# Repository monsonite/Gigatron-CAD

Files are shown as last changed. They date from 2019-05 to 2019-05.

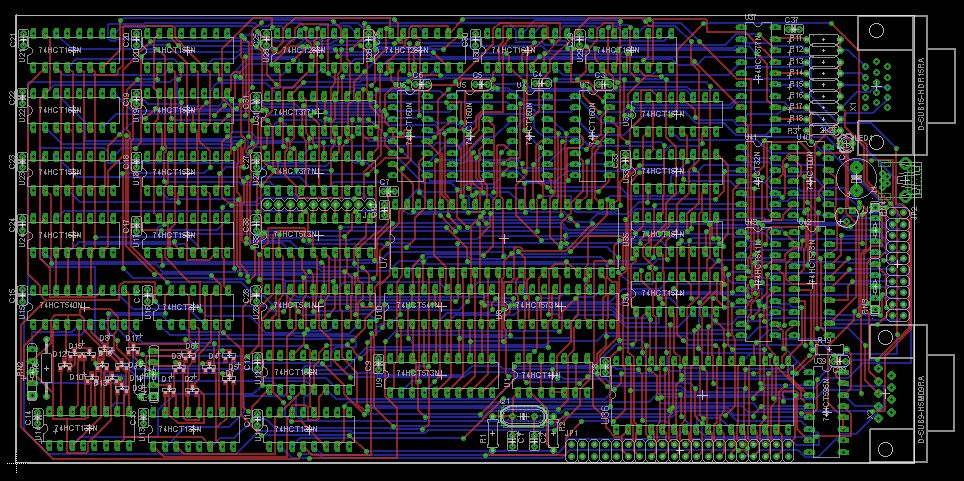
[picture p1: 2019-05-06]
Gig_8.JPG

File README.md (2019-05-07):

# Gigatron-CAD
Eagle CAD Files for the Gigatron TTL Computer - Based on the design by Marcel van Kervinck

These files contain the Gigatron TTL computer schematics transcribed to Eagle CAD - using the IC numbers used in the original KiCAD.

For anyone wanting to build a machine based on the Gigatron design, the Eagle CAD schematic offers a known starting point.

Minor alterations have been made to allow easier routing specifically in the ALU section, where all 74HCT153 multiplexers use the same multiplexer section - and the logic constants into the other mux are the same for all devices.

There are both PDF and PNG overviews of the ALU and Memory sections - a convenient way of representing the complete design.

Certain components substitutions have been made for convenience of layout or saving space

74HCT273 has been exchanged for the more bus friendly 74HCT573

74HCT240 and 74HCT244 have been exchanged for 74F540 and 74F541 - again to give better bus flow.

The diode matrix in the control unit now uses SOT-23 dual common anode diodes to reduce space

If you want to make a very compact Gigatron using 74F series SMT packages, Eagle CAD allows all of the major IC packages to be easily swapped to their SMT equivalents

Gigatron has been run at between 12.5 and 15MHz using 74F series ICS

The 128K byte RAM expansion and additional 8-bit input and 8-bit output ports (for SPI) are also included in this version

Use the .sch files at your own risk - I cannot guarantee that they are completely error free.

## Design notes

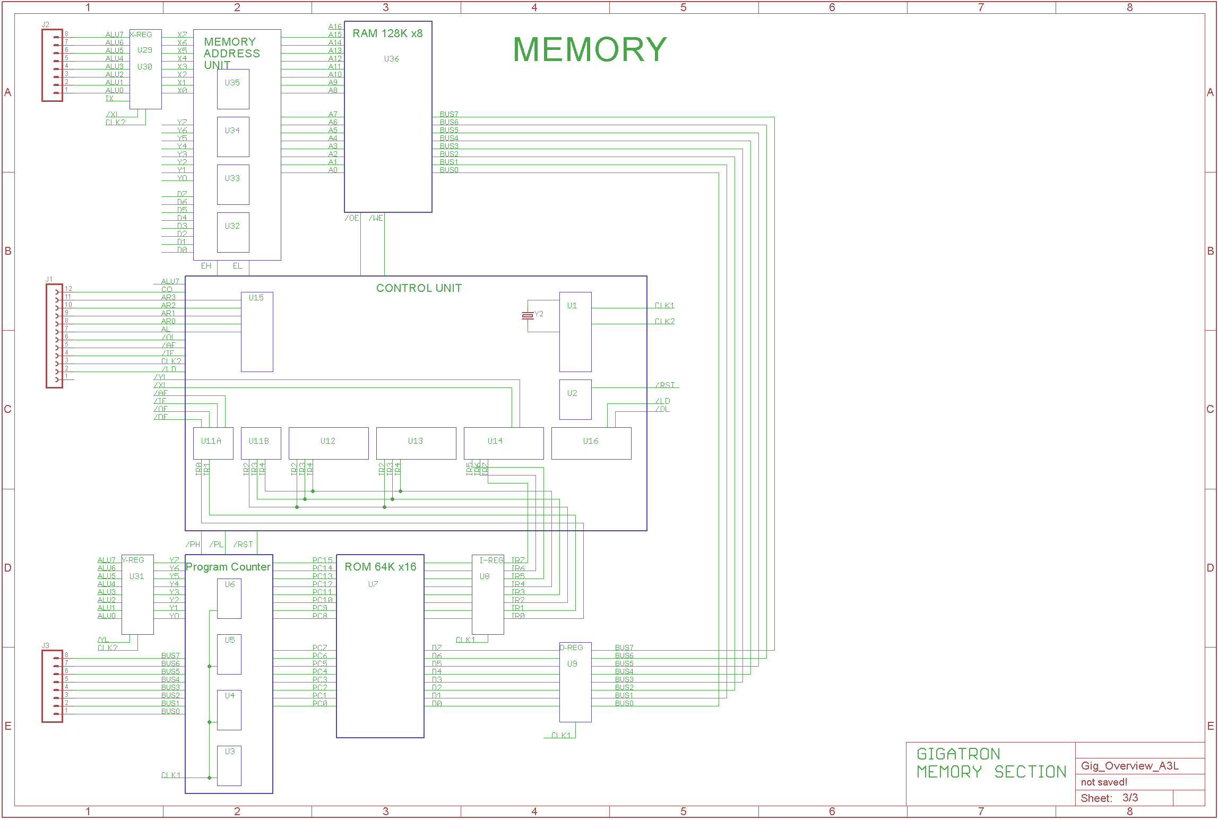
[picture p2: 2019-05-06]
Gig_Memory_A3L.png

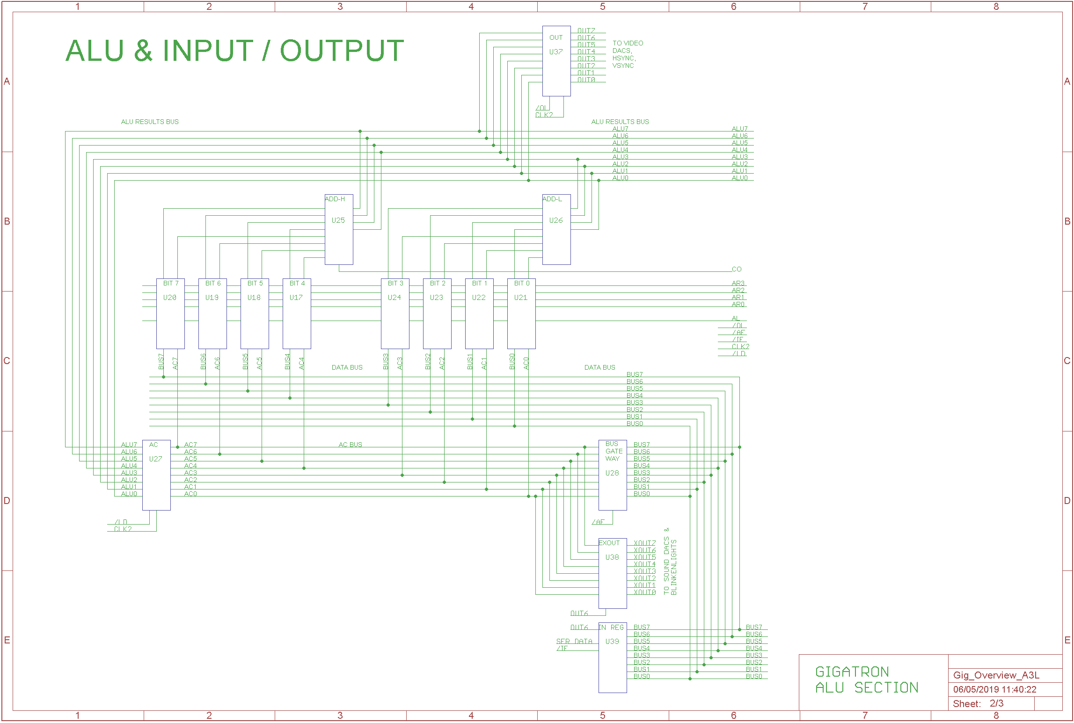
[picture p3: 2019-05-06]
Gig_ALU_A3L.png

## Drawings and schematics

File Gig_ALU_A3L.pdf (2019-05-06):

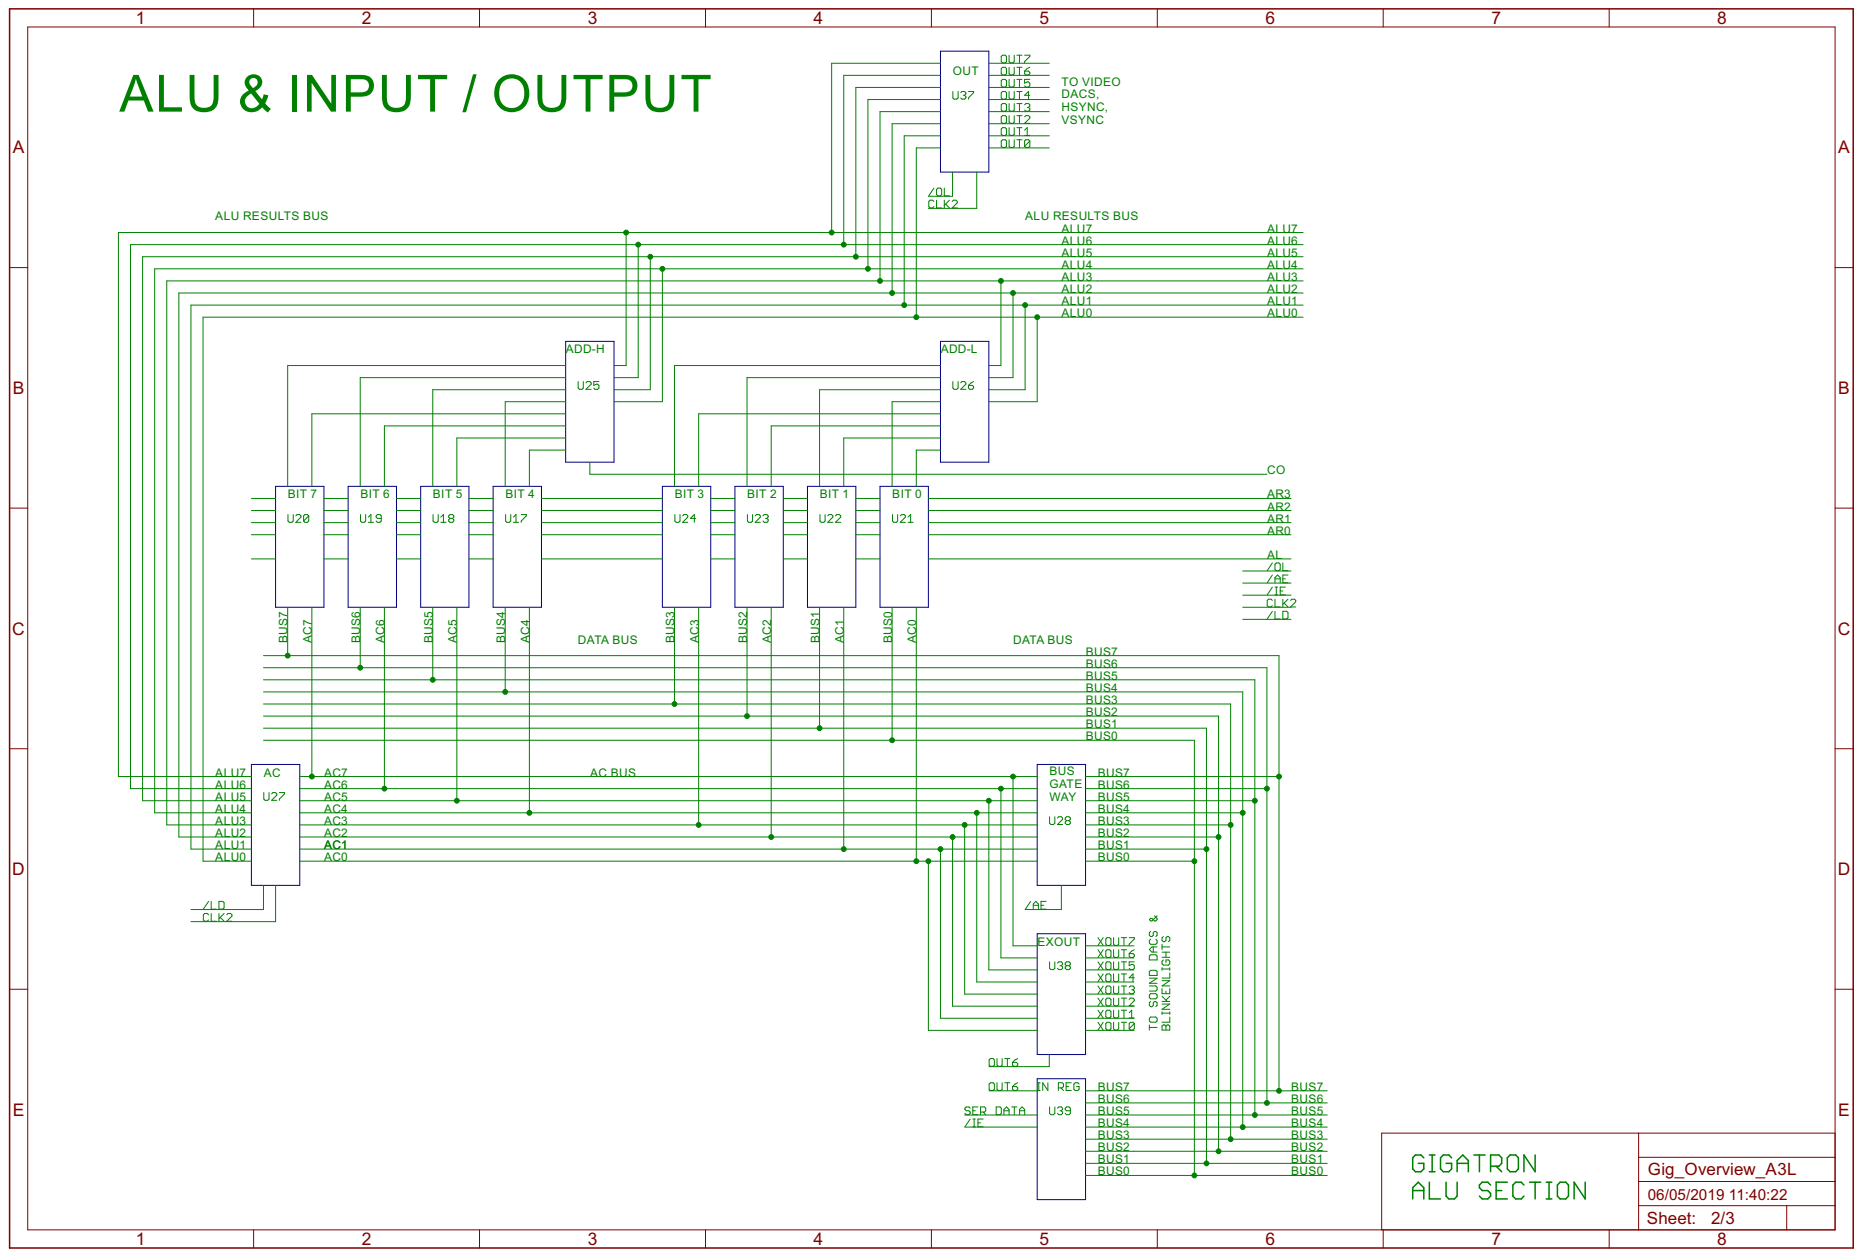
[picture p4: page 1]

BUS6
BUS5
BUS4
BUS3
BUS2
BUS1
BUS0

AC7 | | | AC BUS

ALU6 | | AC6 | | | | | | | | | | BUS6
ALU5 | | AC5 | | | | | | | | | | BUS5
ALU4 | | AC4 | | | | | | | | | | BUS4
ALU3 | | AC3 | | | | | | | | | | BUS3
ALU2 | | AC2 | | | | | | | | | | BUS2
ALU1 | | AC1 | | | | | | | | | | BUS1
ALU0 | | | | | | | | | | | | BUS0

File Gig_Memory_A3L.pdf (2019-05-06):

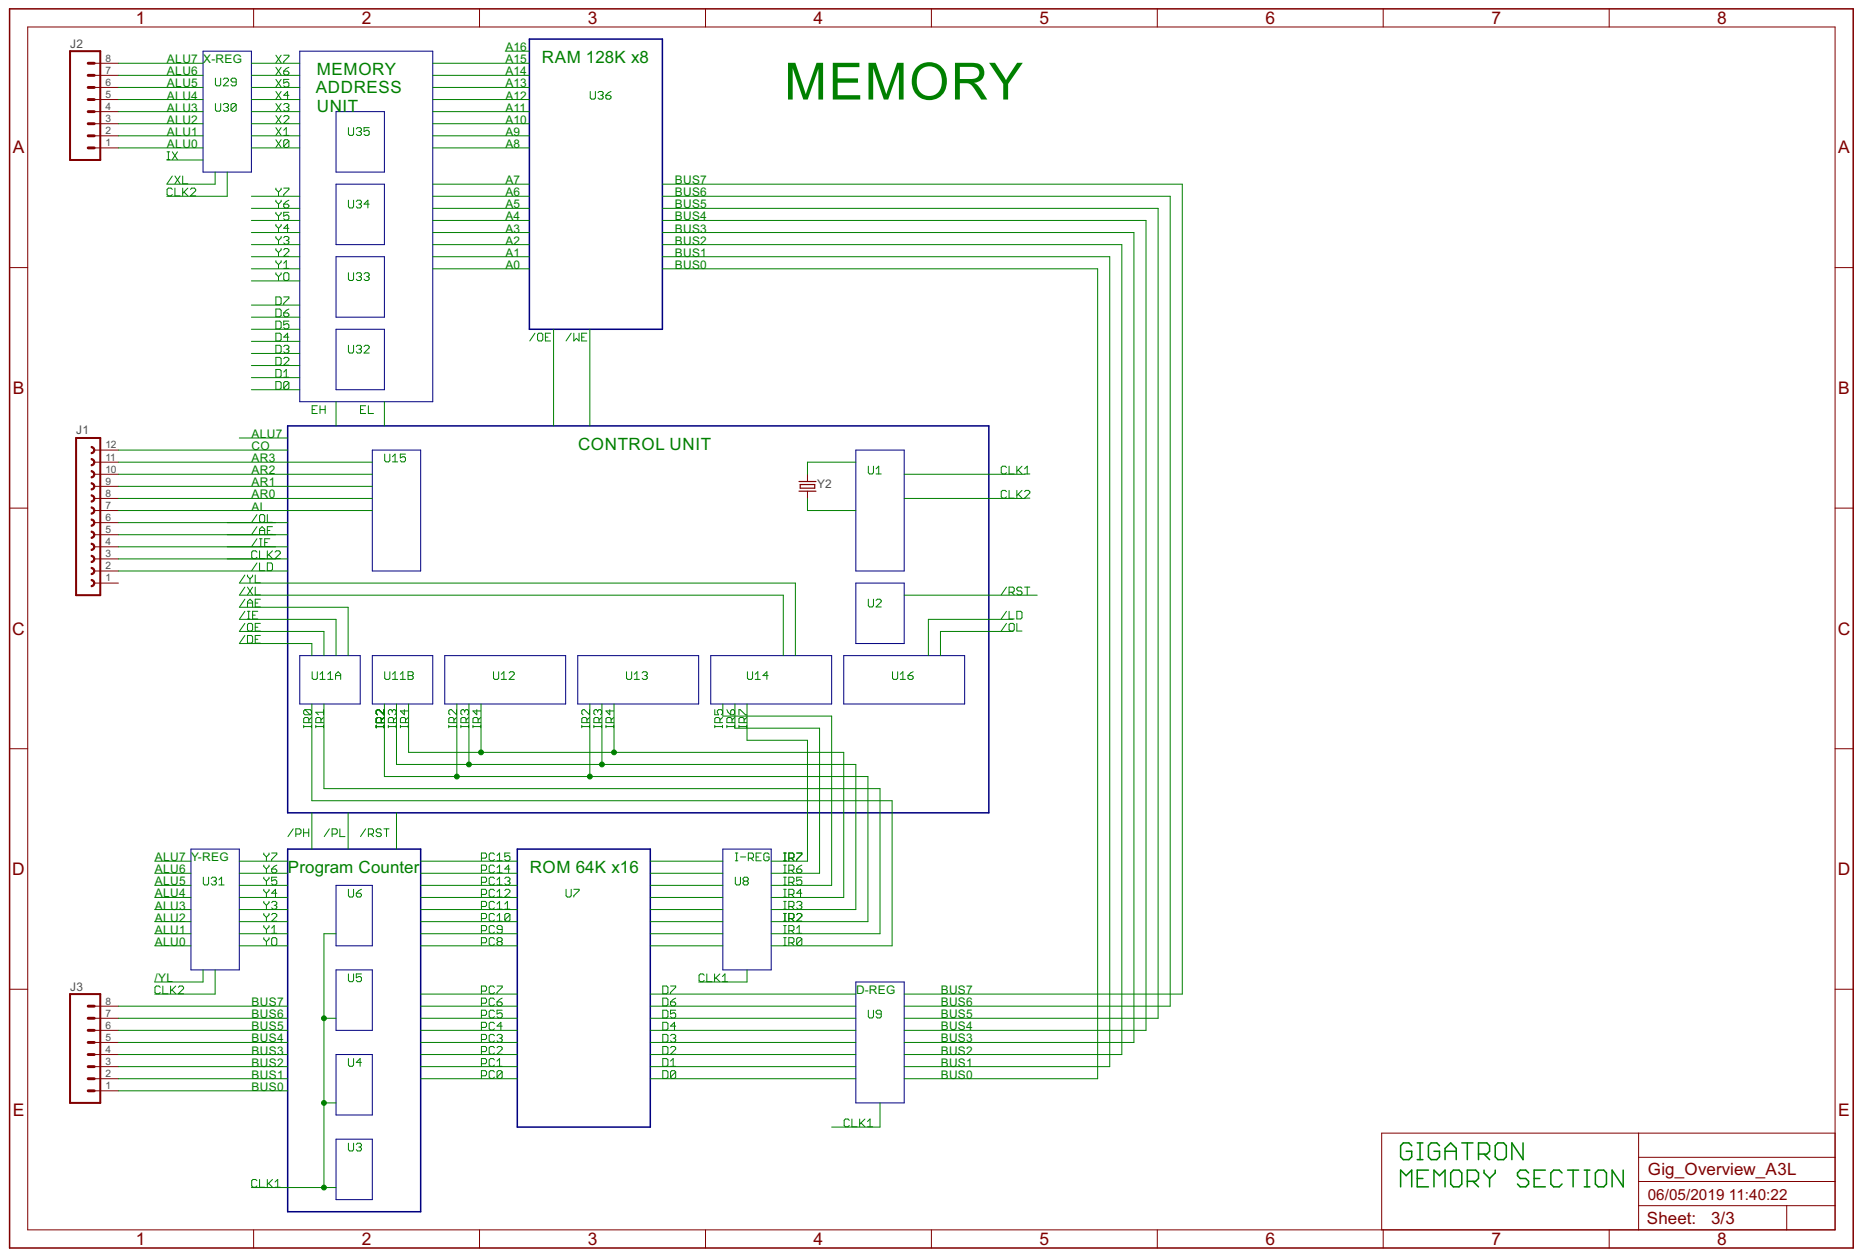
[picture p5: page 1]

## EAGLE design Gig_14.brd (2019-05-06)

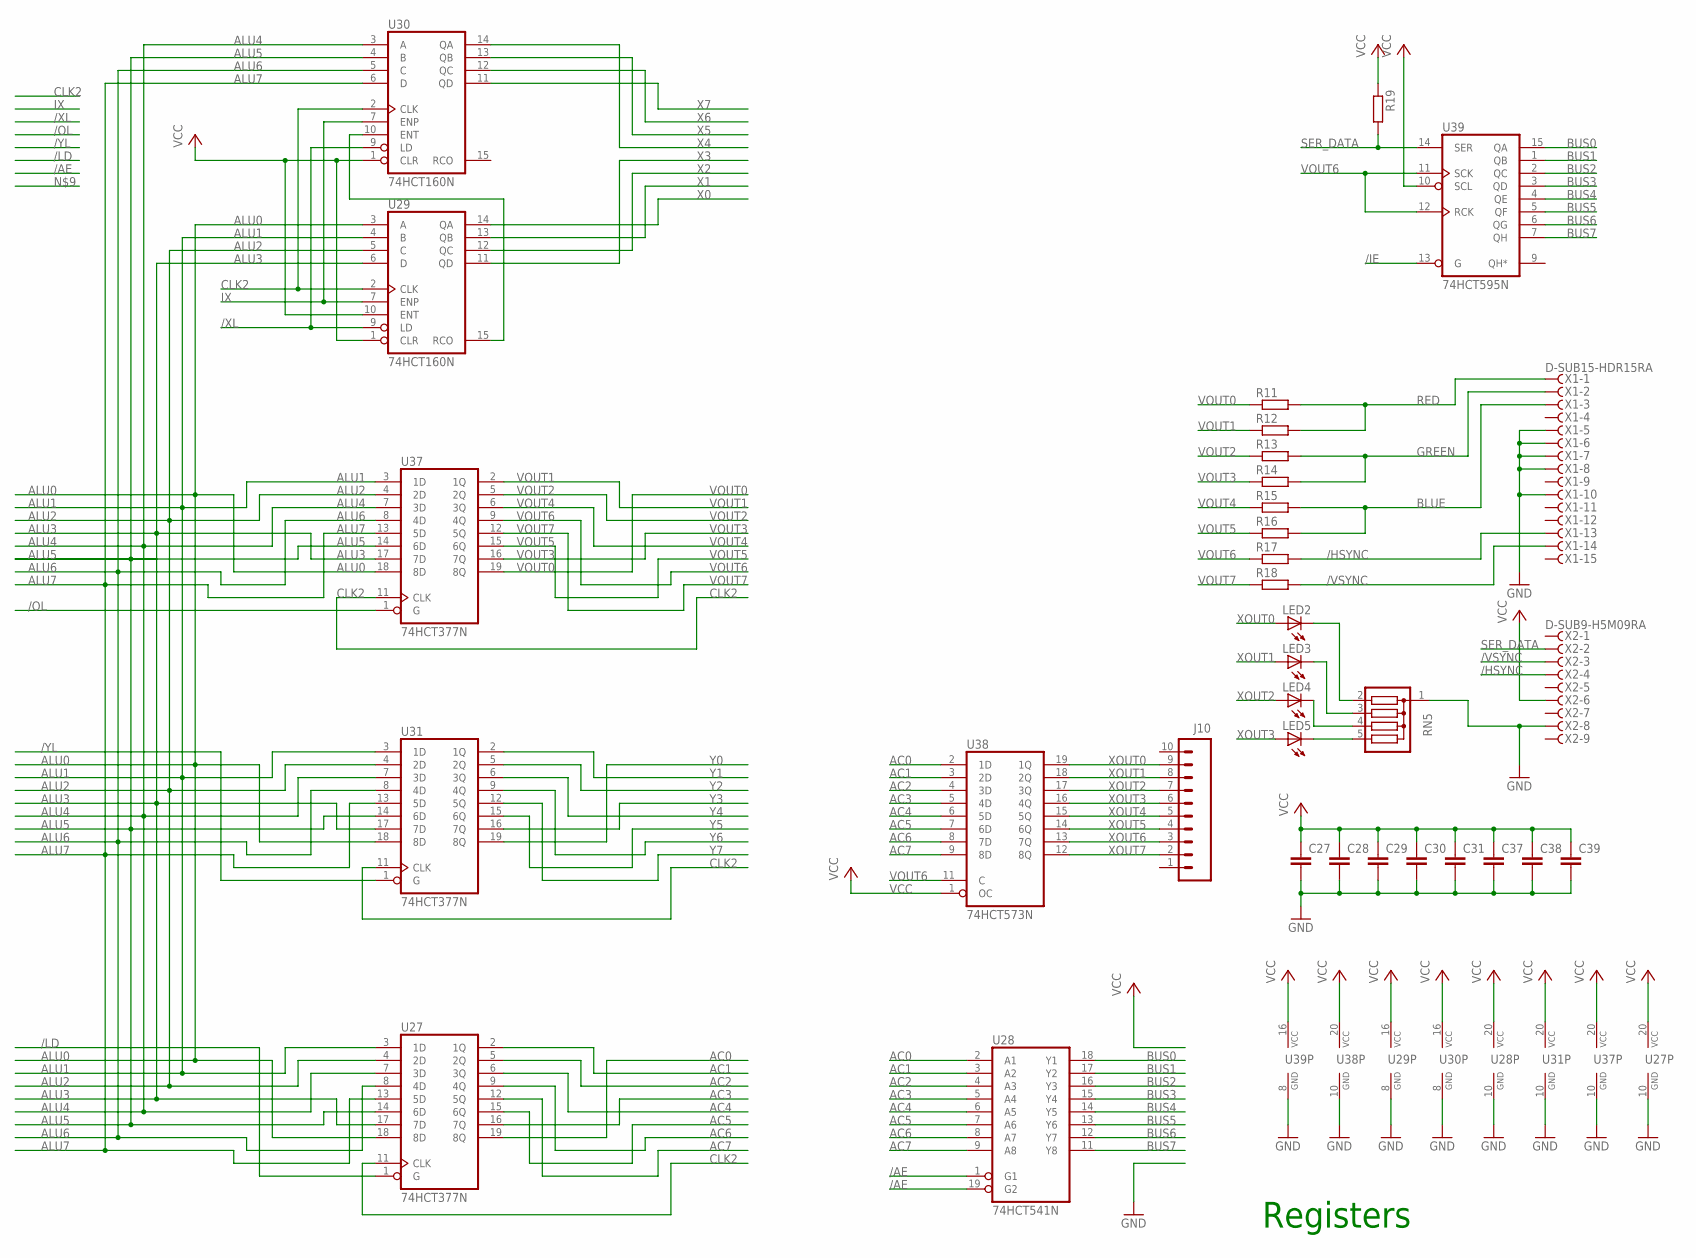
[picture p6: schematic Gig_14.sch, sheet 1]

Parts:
C27, C28, C29, C30, C31, C37, C38, C39: RCL_C-EU025-024X044; RCL_C025-024X044
J10: M10SILK_FEMALE_PTH; 1X10
LED2, LED3, LED4, LED5: LED3MM
R11, R12, R13, R14, R15, R16, R17, R18, R19: R-EU_0207/7; 0207/7
RN5: G04R; SIL5
U27, U31, U37: 74HCT377N; DIL20
U28: 74HCT541N; DIL20
U29, U30: 74HCT160N; DIL16
U38: 74HCT573N; DIL20
U39: 74HCT595N; DIL16
X1: D-SUB15-HDR15RA; HDR15RA
X2: D-SUB9-H5M09RA; H5M09RA

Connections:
/AE: U28.1 (G1), U28.19 (G2); also elsewhere on the board
/HSYNC: R17.2, X1.13, X2.4
/IE: U39.13 (G); also elsewhere on the board
/LD: U27.1 (G); also elsewhere on the board
/OL: U37.1 (G); also elsewhere on the board
/VSYNC: R18.2, X1.14, X2.3
/XL: U29.9 (LD), U30.9 (LD); also elsewhere on the board
/YL: U31.1 (G); also elsewhere on the board
AC0: U27.19 (8Q), U28.2 (A1), U38.2 (1D); also elsewhere on the board
AC1: U27.2 (1Q), U28.3 (A2), U38.3 (2D); also elsewhere on the board
AC2: U27.5 (2Q), U28.4 (A3), U38.4 (3D); also elsewhere on the board
AC3: U27.16 (7Q), U28.5 (A4), U38.5 (4D); also elsewhere on the board
AC4: U27.6 (3Q), U28.6 (A5), U38.6 (5D); also elsewhere on the board
AC5: U27.15 (6Q), U28.7 (A6), U38.7 (6D); also elsewhere on the board
AC6: U27.9 (4Q), U28.8 (A7), U38.8 (7D); also elsewhere on the board
AC7: U27.12 (5Q), U28.9 (A8), U38.9 (8D); also elsewhere on the board
ALU0: U27.18 (8D), U29.3 (A), U31.18 (8D), U37.18 (8D); also elsewhere on the board
ALU1: U27.3 (1D), U29.4 (B), U31.3 (1D), U37.3 (1D); also elsewhere on the board
ALU2: U27.4 (2D), U29.5 (C), U31.4 (2D), U37.4 (2D); also elsewhere on the board
ALU3: U27.17 (7D), U29.6 (D), U31.17 (7D), U37.17 (7D); also elsewhere on the board
ALU4: U27.7 (3D), U30.3 (A), U31.7 (3D), U37.7 (3D); also elsewhere on the board
ALU5: U27.14 (6D), U30.4 (B), U31.14 (6D), U37.14 (6D); also elsewhere on the board
ALU6: U27.8 (4D), U30.5 (C), U31.8 (4D), U37.8 (4D); also elsewhere on the board
ALU7: U27.13 (5D), U30.6 (D), U31.13 (5D), U37.13 (5D); also elsewhere on the board
BLUE: R15.2, R16.2, X1.3
BUS0: U28.18 (Y1), U39.15 (QA); also elsewhere on the board
BUS1: U28.17 (Y2), U39.1 (QB); also elsewhere on the board
BUS2: U28.16 (Y3), U39.2 (QC); also elsewhere on the board
BUS3: U28.15 (Y4), U39.3 (QD); also elsewhere on the board
BUS4: U28.14 (Y5), U39.4 (QE); also elsewhere on the board
BUS5: U28.13 (Y6), U39.5 (QF); also elsewhere on the board
BUS6: U28.12 (Y7), U39.6 (QG); also elsewhere on the board
BUS7: U28.11 (Y8), U39.7 (QH); also elsewhere on the board
CLK2: U27.11 (CLK), U29.2 (CLK), U30.2 (CLK), U31.11 (CLK), U37.11 (CLK); also elsewhere on the board
GND: C27.2, C28.2, C29.2, C30.2, C31.2, C37.2, C38.2, C39.2, RN5.1, U27.10 (GND), U28.10 (GND), U29.8 (GND), U30.8 (GND), U31.10 (GND), U37.10 (GND), U38.10 (GND), U39.8 (GND), X1.5, X1.6, X1.7, X1.8, X1.10, X2.8; also elsewhere on the board
GREEN: R13.2, R14.2, X1.2
IX: U29.7 (ENP), U30.7 (ENP); also elsewhere on the board
unnamed: U29.15 (RCO), U30.10 (ENT)
unnamed: LED2.K (C), RN5.2
unnamed: LED3.K (C), RN5.3
unnamed: LED4.K (C), RN5.4
unnamed: LED5.K (C), RN5.5
RED: R11.2, R12.2, X1.1
SER_DATA: R19.2, U39.14 (SER), X2.2
VCC: C27.1, C28.1, C29.1, C30.1, C31.1, C37.1, C38.1, C39.1, R19.1, U27.20 (VCC), U28.20 (VCC), U29.1 (CLR), U29.10 (ENT), U29.16 (VCC), U30.1 (CLR), U30.16 (VCC), U31.20 (VCC), U37.20 (VCC), U38.1 (OC), U38.20 (VCC), U39.10 (SCL), U39.16 (VCC), X2.6; also elsewhere on the board
VOUT0: R11.1, U37.19 (8Q)
VOUT1: R12.1, U37.2 (1Q)
VOUT2: R13.1, U37.5 (2Q)
VOUT3: R14.1, U37.16 (7Q)
VOUT4: R15.1, U37.6 (3Q)
VOUT5: R16.1, U37.15 (6Q)
VOUT6: R17.1, U37.9 (4Q), U38.11 (C), U39.11 (SCK), U39.12 (RCK)
VOUT7: R18.1, U37.12 (5Q)
X0: U29.14 (QA); also elsewhere on the board
X1: U29.13 (QB); also elsewhere on the board
X2: U29.12 (QC); also elsewhere on the board
X3: U29.11 (QD); also elsewhere on the board
X4: U30.14 (QA); also elsewhere on the board
X5: U30.13 (QB); also elsewhere on the board
X6: U30.12 (QC); also elsewhere on the board
X7: U30.11 (QD); also elsewhere on the board
XOUT0: J10.9, LED2.A, U38.19 (1Q)
XOUT1: J10.8, LED3.A, U38.18 (2Q)
XOUT2: J10.7, LED4.A, U38.17 (3Q)
XOUT3: J10.6, LED5.A, U38.16 (4Q)
XOUT4: J10.5, U38.15 (5Q)
XOUT5: J10.4, U38.14 (6Q)
XOUT6: J10.3, U38.13 (7Q)
XOUT7: J10.2, U38.12 (8Q)
Y0: U31.19 (8Q); also elsewhere on the board
Y1: U31.2 (1Q); also elsewhere on the board
Y2: U31.5 (2Q); also elsewhere on the board
Y3: U31.16 (7Q); also elsewhere on the board
Y4: U31.6 (3Q); also elsewhere on the board
Y5: U31.15 (6Q); also elsewhere on the board
Y6: U31.9 (4Q); also elsewhere on the board
Y7: U31.12 (5Q); also elsewhere on the board

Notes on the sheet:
Registers

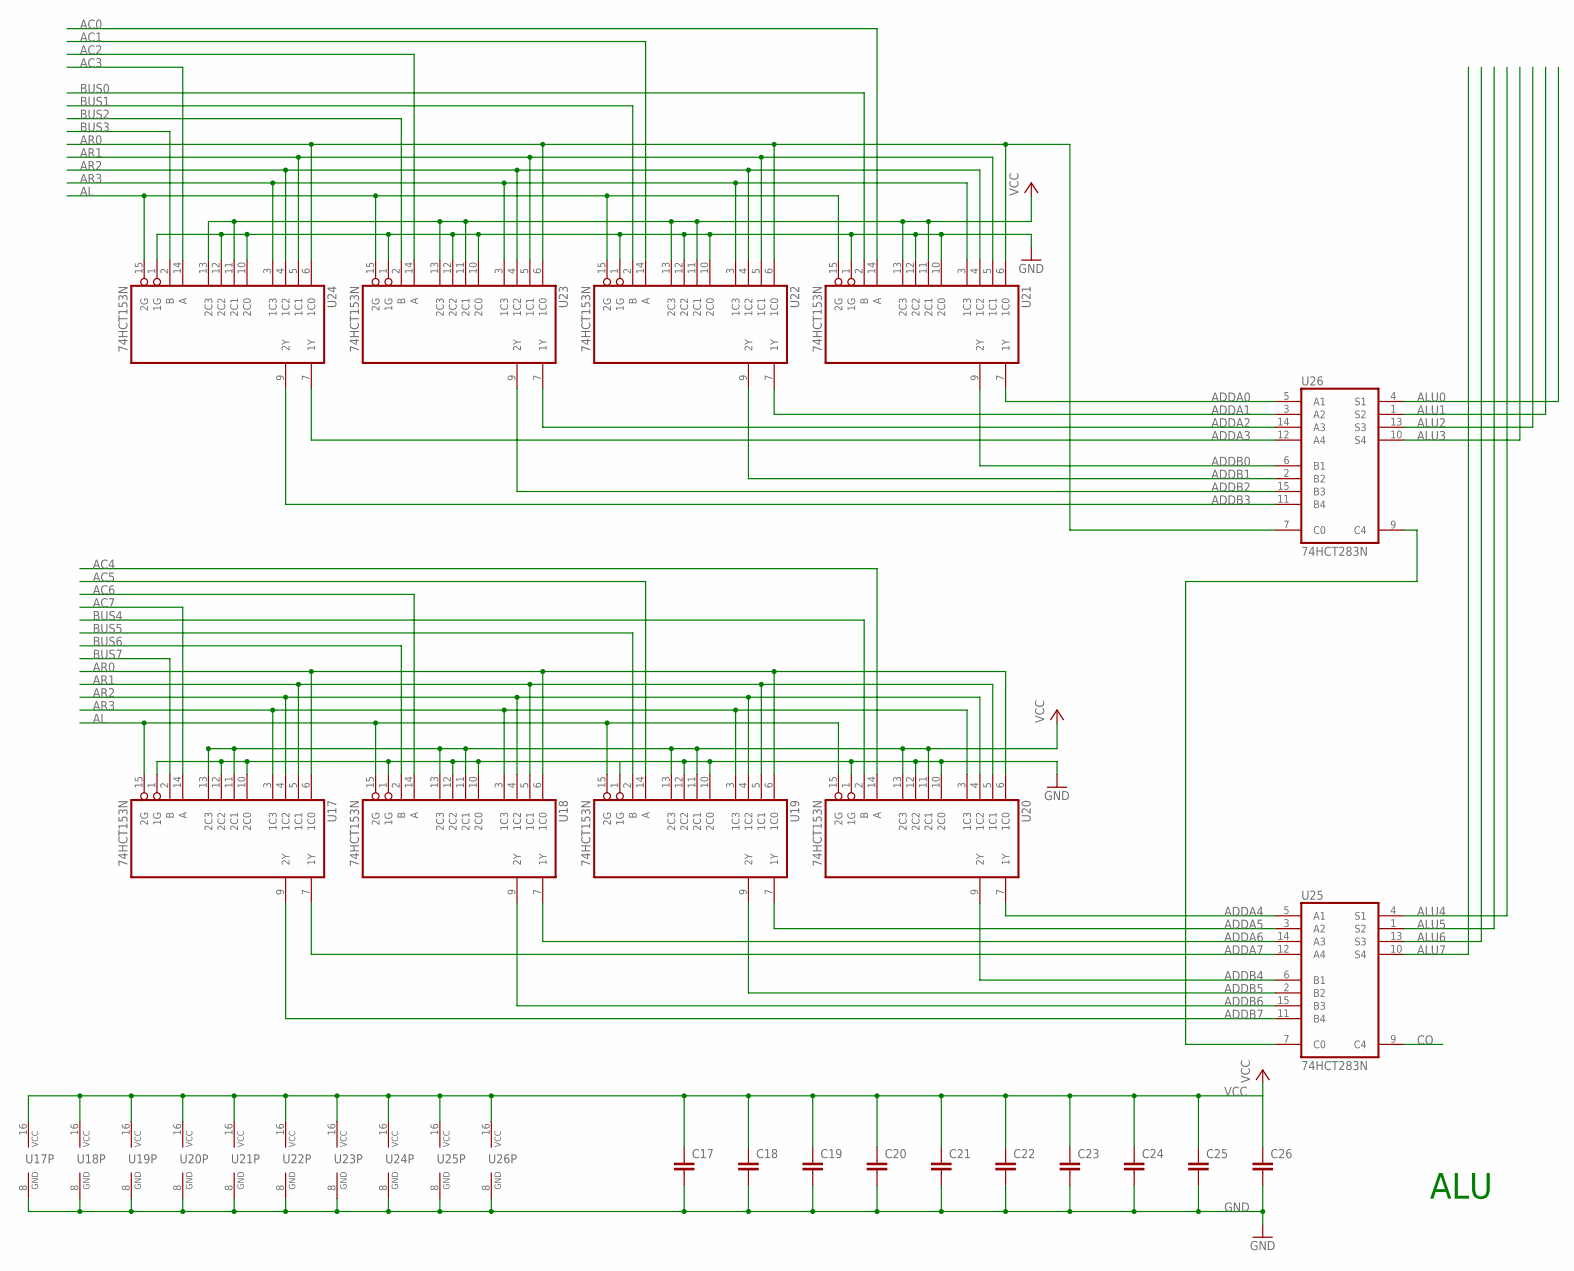
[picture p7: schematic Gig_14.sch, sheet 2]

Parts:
C17, C18, C19, C20, C21, C22, C23, C24, C25, C26: RCL_C-EU025-024X044; RCL_C025-024X044
U17, U18, U19, U20, U21, U22, U23, U24: 74HCT153N; DIL16
U25, U26: 74HCT283N; DIL16

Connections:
AC0: U21.14 (A); also elsewhere on the board
AC1: U22.14 (A); also elsewhere on the board
AC2: U23.14 (A); also elsewhere on the board
AC3: U24.14 (A); also elsewhere on the board
AC4: U20.14 (A); also elsewhere on the board
AC5: U19.14 (A); also elsewhere on the board
AC6: U18.14 (A); also elsewhere on the board
AC7: U17.14 (A); also elsewhere on the board
ADDA0: U21.7 (1Y), U26.5 (A1)
ADDA1: U22.7 (1Y), U26.3 (A2)
ADDA2: U23.7 (1Y), U26.14 (A3)
ADDA3: U24.7 (1Y), U26.12 (A4)
ADDA4: U20.7 (1Y), U25.5 (A1)
ADDA5: U19.7 (1Y), U25.3 (A2)
ADDA6: U18.7 (1Y), U25.14 (A3)
ADDA7: U17.7 (1Y), U25.12 (A4)
ADDB0: U21.9 (2Y), U26.6 (B1)
ADDB1: U22.9 (2Y), U26.2 (B2)
ADDB2: U23.9 (2Y), U26.15 (B3)
ADDB3: U24.9 (2Y), U26.11 (B4)
ADDB4: U20.9 (2Y), U25.6 (B1)
ADDB5: U19.9 (2Y), U25.2 (B2)
ADDB6: U18.9 (2Y), U25.15 (B3)
ADDB7: U17.9 (2Y), U25.11 (B4)
AL: U17.15 (2G), U18.15 (2G), U19.15 (2G), U20.15 (2G), U21.15 (2G), U22.15 (2G), U23.15 (2G), U24.15 (2G); also elsewhere on the board
ALU0: U26.4 (S1); also elsewhere on the board
ALU1: U26.1 (S2); also elsewhere on the board
ALU2: U26.13 (S3); also elsewhere on the board
ALU3: U26.10 (S4); also elsewhere on the board
ALU4: U25.4 (S1); also elsewhere on the board
ALU5: U25.1 (S2); also elsewhere on the board
ALU6: U25.13 (S3); also elsewhere on the board
ALU7: U25.10 (S4); also elsewhere on the board
AR0: U17.6 (1C0), U18.6 (1C0), U19.6 (1C0), U20.6 (1C0), U21.6 (1C0), U22.6 (1C0), U23.6 (1C0), U24.6 (1C0), U26.7 (C0); also elsewhere on the board
AR1: U17.5 (1C1), U18.5 (1C1), U19.5 (1C1), U20.5 (1C1), U21.5 (1C1), U22.5 (1C1), U23.5 (1C1), U24.5 (1C1); also elsewhere on the board
AR2: U17.4 (1C2), U18.4 (1C2), U19.4 (1C2), U20.4 (1C2), U21.4 (1C2), U22.4 (1C2), U23.4 (1C2), U24.4 (1C2); also elsewhere on the board
AR3: U17.3 (1C3), U18.3 (1C3), U19.3 (1C3), U20.3 (1C3), U21.3 (1C3), U22.3 (1C3), U23.3 (1C3), U24.3 (1C3); also elsewhere on the board
BUS0: U21.2 (B); also elsewhere on the board
BUS1: U22.2 (B); also elsewhere on the board
BUS2: U23.2 (B); also elsewhere on the board
BUS3: U24.2 (B); also elsewhere on the board
BUS4: U20.2 (B); also elsewhere on the board
BUS5: U19.2 (B); also elsewhere on the board
BUS6: U18.2 (B); also elsewhere on the board
BUS7: U17.2 (B); also elsewhere on the board
CO: U25.9 (C4); also elsewhere on the board
GND: C17.2, C18.2, C19.2, C20.2, C21.2, C22.2, C23.2, C24.2, C25.2, C26.2, U17.1 (1G), U17.8 (GND), U17.10 (2C0), U17.12 (2C2), U18.1 (1G), U18.8 (GND), U18.10 (2C0), U18.12 (2C2), U19.1 (1G), U19.8 (GND), U19.10 (2C0), U19.12 (2C2), U20.1 (1G), U20.8 (GND), U20.10 (2C0), U20.12 (2C2), U21.1 (1G), U21.8 (GND), U21.10 (2C0), U21.12 (2C2), U22.1 (1G), U22.8 (GND), U22.10 (2C0), U22.12 (2C2), U23.1 (1G), U23.8 (GND), U23.10 (2C0), U23.12 (2C2), U24.1 (1G), U24.8 (GND), U24.10 (2C0), U24.12 (2C2), U25.8 (GND), U26.8 (GND); also elsewhere on the board
unnamed: U25.7 (C0), U26.9 (C4)
VCC: C17.1, C18.1, C19.1, C20.1, C21.1, C22.1, C23.1, C24.1, C25.1, C26.1, U17.11 (2C1), U17.13 (2C3), U17.16 (VCC), U18.11 (2C1), U18.13 (2C3), U18.16 (VCC), U19.11 (2C1), U19.13 (2C3), U19.16 (VCC), U20.11 (2C1), U20.13 (2C3), U20.16 (VCC), U21.11 (2C1), U21.13 (2C3), U21.16 (VCC), U22.11 (2C1), U22.13 (2C3), U22.16 (VCC), U23.11 (2C1), U23.13 (2C3), U23.16 (VCC), U24.11 (2C1), U24.13 (2C3), U24.16 (VCC), U25.16 (VCC), U26.16 (VCC); also elsewhere on the board

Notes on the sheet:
ALU

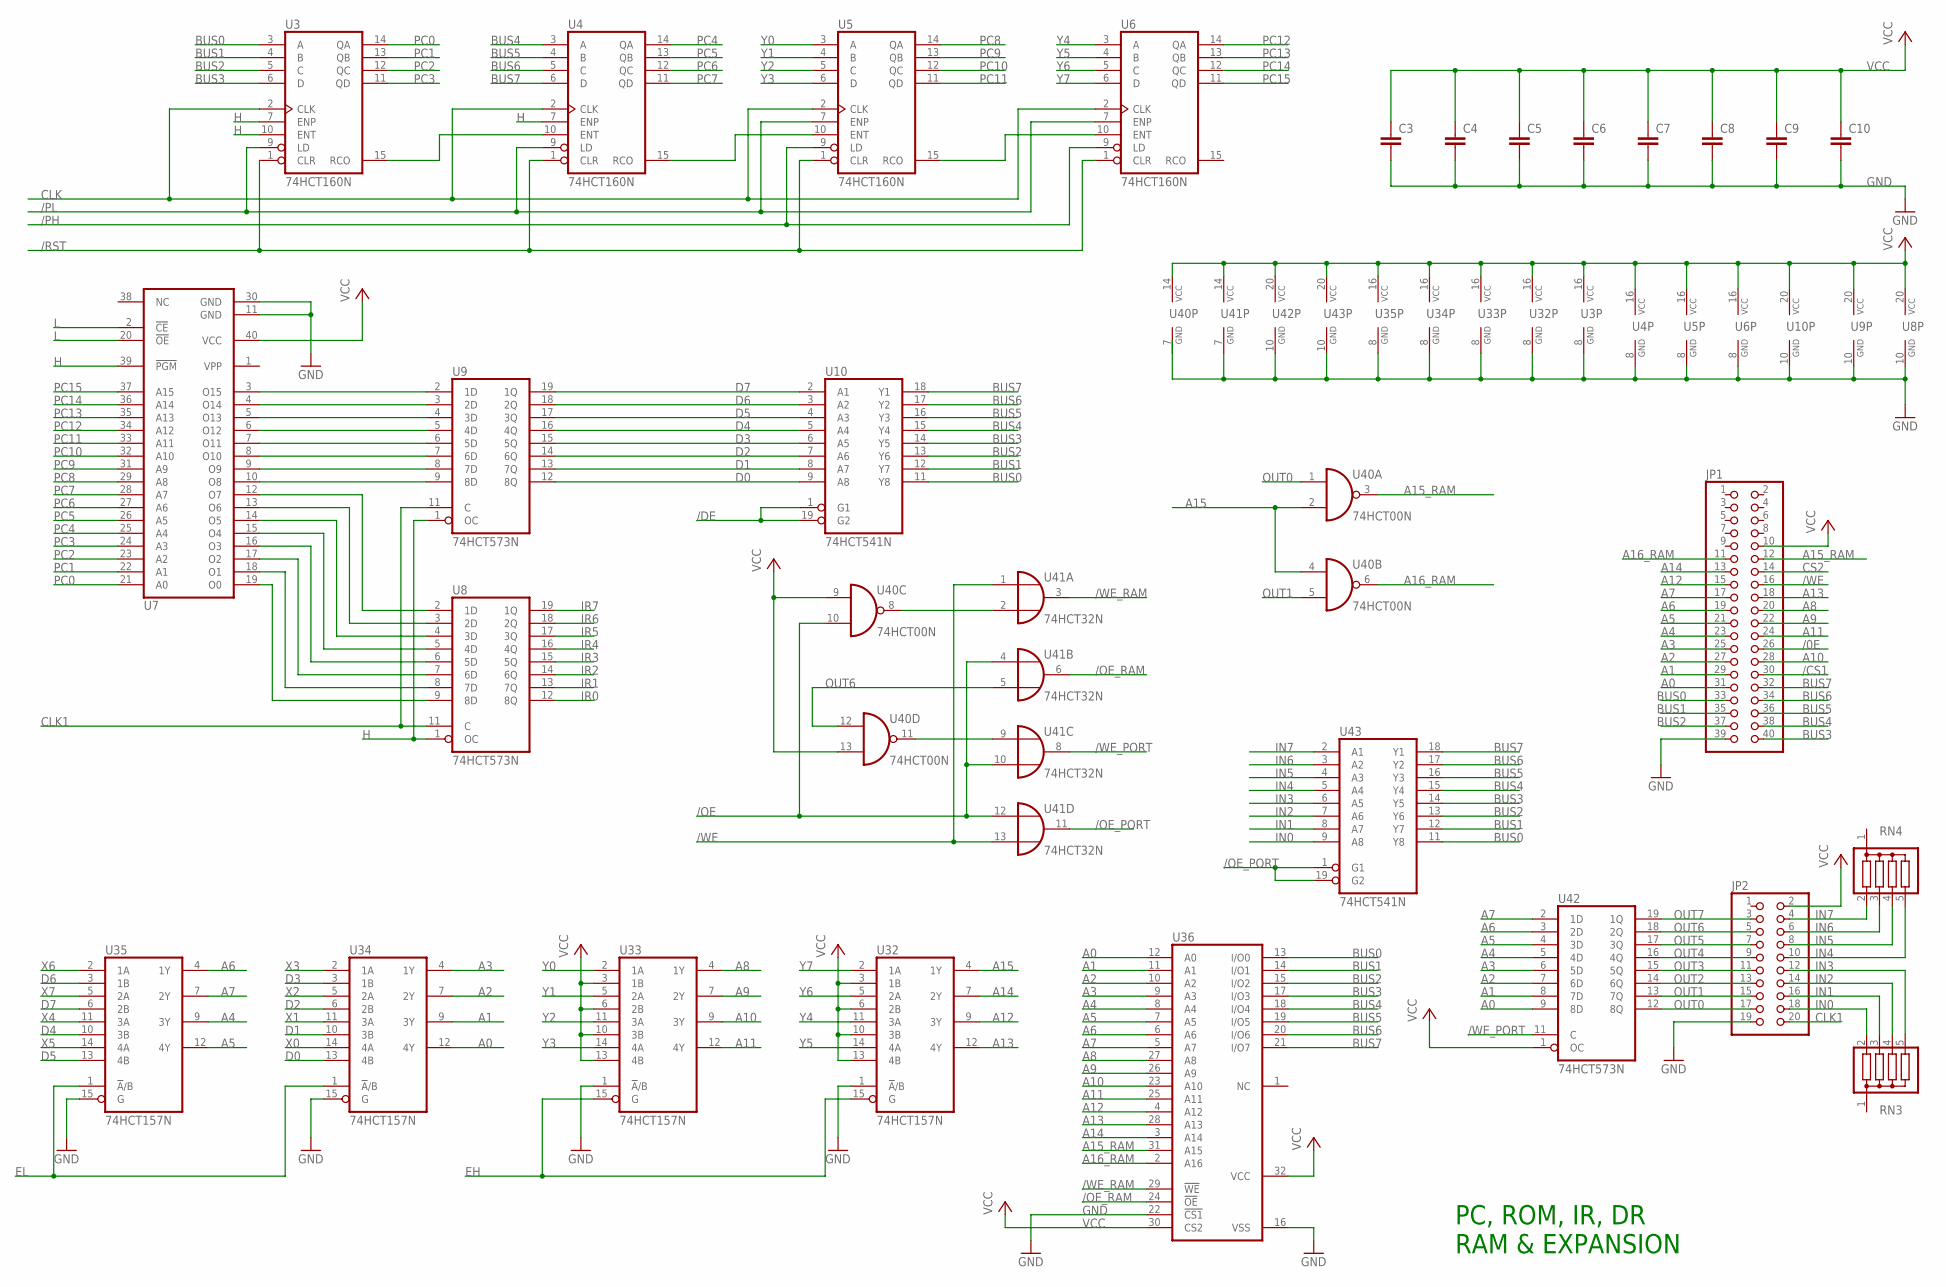
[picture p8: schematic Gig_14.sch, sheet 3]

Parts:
C3, C4, C5, C6, C7, C8, C9, C10: RCL_C-EU025-024X044; RCL_C025-024X044
JP1: PINHD-2X20; 2X20
JP2: PINHD-2X10; 2X10
RN3, RN4: G04R; SIL5
U3, U4, U5, U6: 74HCT160N; DIL16
U7: 27C1024D; DIL40
U8, U9, U42: 74HCT573N; DIL20
U10, U43: 74HCT541N; DIL20
U32, U33, U34, U35: 74HCT157N; DIL16
U36: 628128P; DIL32
U40: 74HCT00N; DIL14
U41: 74HCT32N; DIL14

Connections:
/0E: JP1.26
/CS1: JP1.30
/DE: U10.1 (G1), U10.19 (G2); also elsewhere on the board
/OE: U40.10 (I1), U41.4 (I0), U41.10 (I1), U41.12 (I0); also elsewhere on the board
/OE_PORT: U41.11 (O), U43.1 (G1), U43.19 (G2)
/OE_RAM: U36.24 (!OE), U41.6 (O)
/PH: U5.9 (LD), U6.9 (LD); also elsewhere on the board
/PL: U3.9 (LD), U4.9 (LD), U5.7 (ENP), U6.7 (ENP); also elsewhere on the board
/RST: U3.1 (CLR), U4.1 (CLR), U5.1 (CLR), U6.1 (CLR); also elsewhere on the board
/WE: JP1.16, U41.1 (I0), U41.13 (I1); also elsewhere on the board
/WE_PORT: U41.8 (O), U42.11 (C)
/WE_RAM: U36.29 (!WE), U41.3 (O)
A0: JP1.31, U34.12 (4Y), U36.12 (A0), U42.9 (8D)
A1: JP1.29, U34.9 (3Y), U36.11 (A1), U42.8 (7D)
A2: JP1.27, U34.7 (2Y), U36.10 (A2), U42.7 (6D)
A3: JP1.25, U34.4 (1Y), U36.9 (A3), U42.6 (5D)
A4: JP1.23, U35.9 (3Y), U36.8 (A4), U42.5 (4D)
A5: JP1.21, U35.12 (4Y), U36.7 (A5), U42.4 (3D)
A6: JP1.19, U35.4 (1Y), U36.6 (A6), U42.3 (2D)
A7: JP1.17, U35.7 (2Y), U36.5 (A7), U42.2 (1D)
A8: JP1.20, U33.4 (1Y), U36.27 (A8)
A9: JP1.22, U33.7 (2Y), U36.26 (A9)
A10: JP1.28, U33.9 (3Y), U36.23 (A10)
A11: JP1.24, U33.12 (4Y), U36.25 (A11)
A12: JP1.15, U32.9 (3Y), U36.4 (A12)
A13: JP1.18, U32.12 (4Y), U36.28 (A13)
A14: JP1.13, U32.7 (2Y), U36.3 (A14)
A15: U32.4 (1Y), U40.2 (I1), U40.4 (I0)
A15_RAM: JP1.12, U36.31 (A15), U40.3 (O)
A16_RAM: JP1.11, U36.2 (A16), U40.6 (O)
BUS0: JP1.33, U3.3 (A), U10.11 (Y8), U36.13 (I/O0), U43.11 (Y8); also elsewhere on the board
BUS1: JP1.35, U3.4 (B), U10.12 (Y7), U36.14 (I/O1), U43.12 (Y7); also elsewhere on the board
BUS2: JP1.37, U3.5 (C), U10.13 (Y6), U36.15 (I/O2), U43.13 (Y6); also elsewhere on the board
BUS3: JP1.40, U3.6 (D), U10.14 (Y5), U36.17 (I/O3), U43.14 (Y5); also elsewhere on the board
BUS4: JP1.38, U4.3 (A), U10.15 (Y4), U36.18 (I/O4), U43.15 (Y4); also elsewhere on the board
BUS5: JP1.36, U4.4 (B), U10.16 (Y3), U36.19 (I/O5), U43.16 (Y3); also elsewhere on the board
BUS6: JP1.34, U4.5 (C), U10.17 (Y2), U36.20 (I/O6), U43.17 (Y2); also elsewhere on the board
BUS7: JP1.32, U4.6 (D), U10.18 (Y1), U36.21 (I/O7), U43.18 (Y1); also elsewhere on the board
CLK: U3.2 (CLK), U4.2 (CLK), U5.2 (CLK), U6.2 (CLK)
CLK1: JP2.20, U8.11 (C), U9.11 (C); also elsewhere on the board
CS2: JP1.14
D0: U9.12 (8Q), U10.9 (A8), U34.13 (4B)
D1: U9.13 (7Q), U10.8 (A7), U34.10 (3B)
D2: U9.14 (6Q), U10.7 (A6), U34.6 (2B)
D3: U9.15 (5Q), U10.6 (A5), U34.3 (1B)
D4: U9.16 (4Q), U10.5 (A4), U35.10 (3B)
D5: U9.17 (3Q), U10.4 (A3), U35.13 (4B)
D6: U9.18 (2Q), U10.3 (A2), U35.3 (1B)
D7: U9.19 (1Q), U10.2 (A1), U35.6 (2B)
EH: U32.15 (G), U33.15 (G); also elsewhere on the board
EL: U34.1 (!A!/B), U35.1 (!A!/B); also elsewhere on the board
GND: C3.2, C4.2, C5.2, C6.2, C7.2, C8.2, C9.2, C10.2, JP1.39, JP2.19, U3.8 (GND), U4.8 (GND), U5.8 (GND), U6.8 (GND), U7.11 (GND), U7.30 (GND), U8.10 (GND), U9.10 (GND), U10.10 (GND), U32.1 (!A!/B), U32.8 (GND), U33.1 (!A!/B), U33.8 (GND), U34.8 (GND), U34.15 (G), U35.8 (GND), U35.15 (G), U36.16 (VSS), U36.22 (!CS1), U40.7 (GND), U41.7 (GND), U42.10 (GND), U43.10 (GND); also elsewhere on the board
H: U3.7 (ENP), U3.10 (ENT), U4.7 (ENP), U7.39 (!PGM), U8.1 (OC), U9.1 (OC)
IN0: JP2.18, RN3.2, U43.9 (A8)
IN1: JP2.16, RN3.3, U43.8 (A7)
IN2: JP2.14, RN3.4, U43.7 (A6)
IN3: JP2.12, RN3.5, U43.6 (A5)
IN4: JP2.10, RN4.5, U43.5 (A4)
IN5: JP2.8, RN4.4, U43.4 (A3)
IN6: JP2.6, RN4.3, U43.3 (A2)
IN7: JP2.4, RN4.2, U43.2 (A1)
IR0: U8.12 (8Q); also elsewhere on the board
IR1: U8.13 (7Q); also elsewhere on the board
IR2: U8.14 (6Q); also elsewhere on the board
IR3: U8.15 (5Q); also elsewhere on the board
IR4: U8.16 (4Q); also elsewhere on the board
IR5: U8.17 (3Q); also elsewhere on the board
IR6: U8.18 (2Q); also elsewhere on the board
IR7: U8.19 (1Q); also elsewhere on the board
L: U7.2 (!CE), U7.20 (!OE)
unnamed: U40.8 (O), U41.2 (I1)
unnamed: U40.11 (O), U41.9 (I0)
unnamed: U7.3 (O15), U9.2 (1D)
unnamed: U7.4 (O14), U9.3 (2D)
unnamed: U7.5 (O13), U9.4 (3D)
unnamed: U7.6 (O12), U9.5 (4D)
unnamed: U7.7 (O11), U9.6 (5D)
unnamed: U7.8 (O10), U9.7 (6D)
unnamed: U7.9 (O9), U9.8 (7D)
unnamed: U7.10 (O8), U9.9 (8D)
unnamed: U7.12 (O7), U8.2 (1D)
unnamed: U7.13 (O6), U8.3 (2D)
unnamed: U7.14 (O5), U8.4 (3D)
unnamed: U7.15 (O4), U8.5 (4D)
unnamed: U7.16 (O3), U8.6 (5D)
unnamed: U7.17 (O2), U8.7 (6D)
unnamed: U7.18 (O1), U8.8 (7D)
unnamed: U7.19 (O0), U8.9 (8D)
unnamed: U3.15 (RCO), U4.10 (ENT)
unnamed: U4.15 (RCO), U5.10 (ENT)
unnamed: U5.15 (RCO), U6.10 (ENT)
OUT0: JP2.17, U40.1 (I0), U42.12 (8Q)
OUT1: JP2.15, U40.5 (I1), U42.13 (7Q)
OUT2: JP2.13, U42.14 (6Q)
OUT3: JP2.11, U42.15 (5Q)
OUT4: JP2.9, U42.16 (4Q)
OUT5: JP2.7, U42.17 (3Q)
OUT6: JP2.5, U40.12 (I0), U41.5 (I1), U42.18 (2Q)
OUT7: JP2.3, U42.19 (1Q)
PC0: U3.14 (QA), U7.21 (A0)
PC1: U3.13 (QB), U7.22 (A1)
PC2: U3.12 (QC), U7.23 (A2)
PC3: U3.11 (QD), U7.24 (A3)
PC4: U4.14 (QA), U7.25 (A4)
PC5: U4.13 (QB), U7.26 (A5)
PC6: U4.12 (QC), U7.27 (A6)
PC7: U4.11 (QD), U7.28 (A7)
PC8: U5.14 (QA), U7.29 (A8)
PC9: U5.13 (QB), U7.31 (A9)
PC10: U5.12 (QC), U7.32 (A10)
PC11: U5.11 (QD), U7.33 (A11)
PC12: U6.14 (QA), U7.34 (A12)
PC13: U6.13 (QB), U7.35 (A13)
PC14: U6.12 (QC), U7.36 (A14)
PC15: U6.11 (QD), U7.37 (A15)
VCC: C3.1, C4.1, C5.1, C6.1, C7.1, C8.1, C9.1, C10.1, JP1.10, JP2.2, U3.16 (VCC), U4.16 (VCC), U5.16 (VCC), U6.16 (VCC), U7.40 (VCC), U8.20 (VCC), U9.20 (VCC), U10.20 (VCC), U32.3 (1B), U32.6 (2B), U32.10 (3B), U32.13 (4B), U32.16 (VCC), U33.3 (1B), U33.6 (2B), U33.10 (3B), U33.13 (4B), U33.16 (VCC), U34.16 (VCC), U35.16 (VCC), U36.30 (CS2), U36.32 (VCC), U40.9 (I0), U40.13 (I1), U40.14 (VCC), U41.14 (VCC), U42.1 (OC), U42.20 (VCC), U43.20 (VCC); also elsewhere on the board
X0: U34.14 (4A); also elsewhere on the board
X1: U34.11 (3A); also elsewhere on the board
X2: U34.5 (2A); also elsewhere on the board
X3: U34.2 (1A); also elsewhere on the board
X4: U35.11 (3A); also elsewhere on the board
X5: U35.14 (4A); also elsewhere on the board
X6: U35.2 (1A); also elsewhere on the board
X7: U35.5 (2A); also elsewhere on the board
Y0: U5.3 (A), U33.2 (1A); also elsewhere on the board
Y1: U5.4 (B), U33.5 (2A); also elsewhere on the board
Y2: U5.5 (C), U33.11 (3A); also elsewhere on the board
Y3: U5.6 (D), U33.14 (4A); also elsewhere on the board
Y4: U6.3 (A), U32.11 (3A); also elsewhere on the board
Y5: U6.4 (B), U32.14 (4A); also elsewhere on the board
Y6: U6.5 (C), U32.5 (2A); also elsewhere on the board
Y7: U6.6 (D), U32.2 (1A); also elsewhere on the board

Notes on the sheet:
PC, ROM, IR, DR RAM & EXPANSION

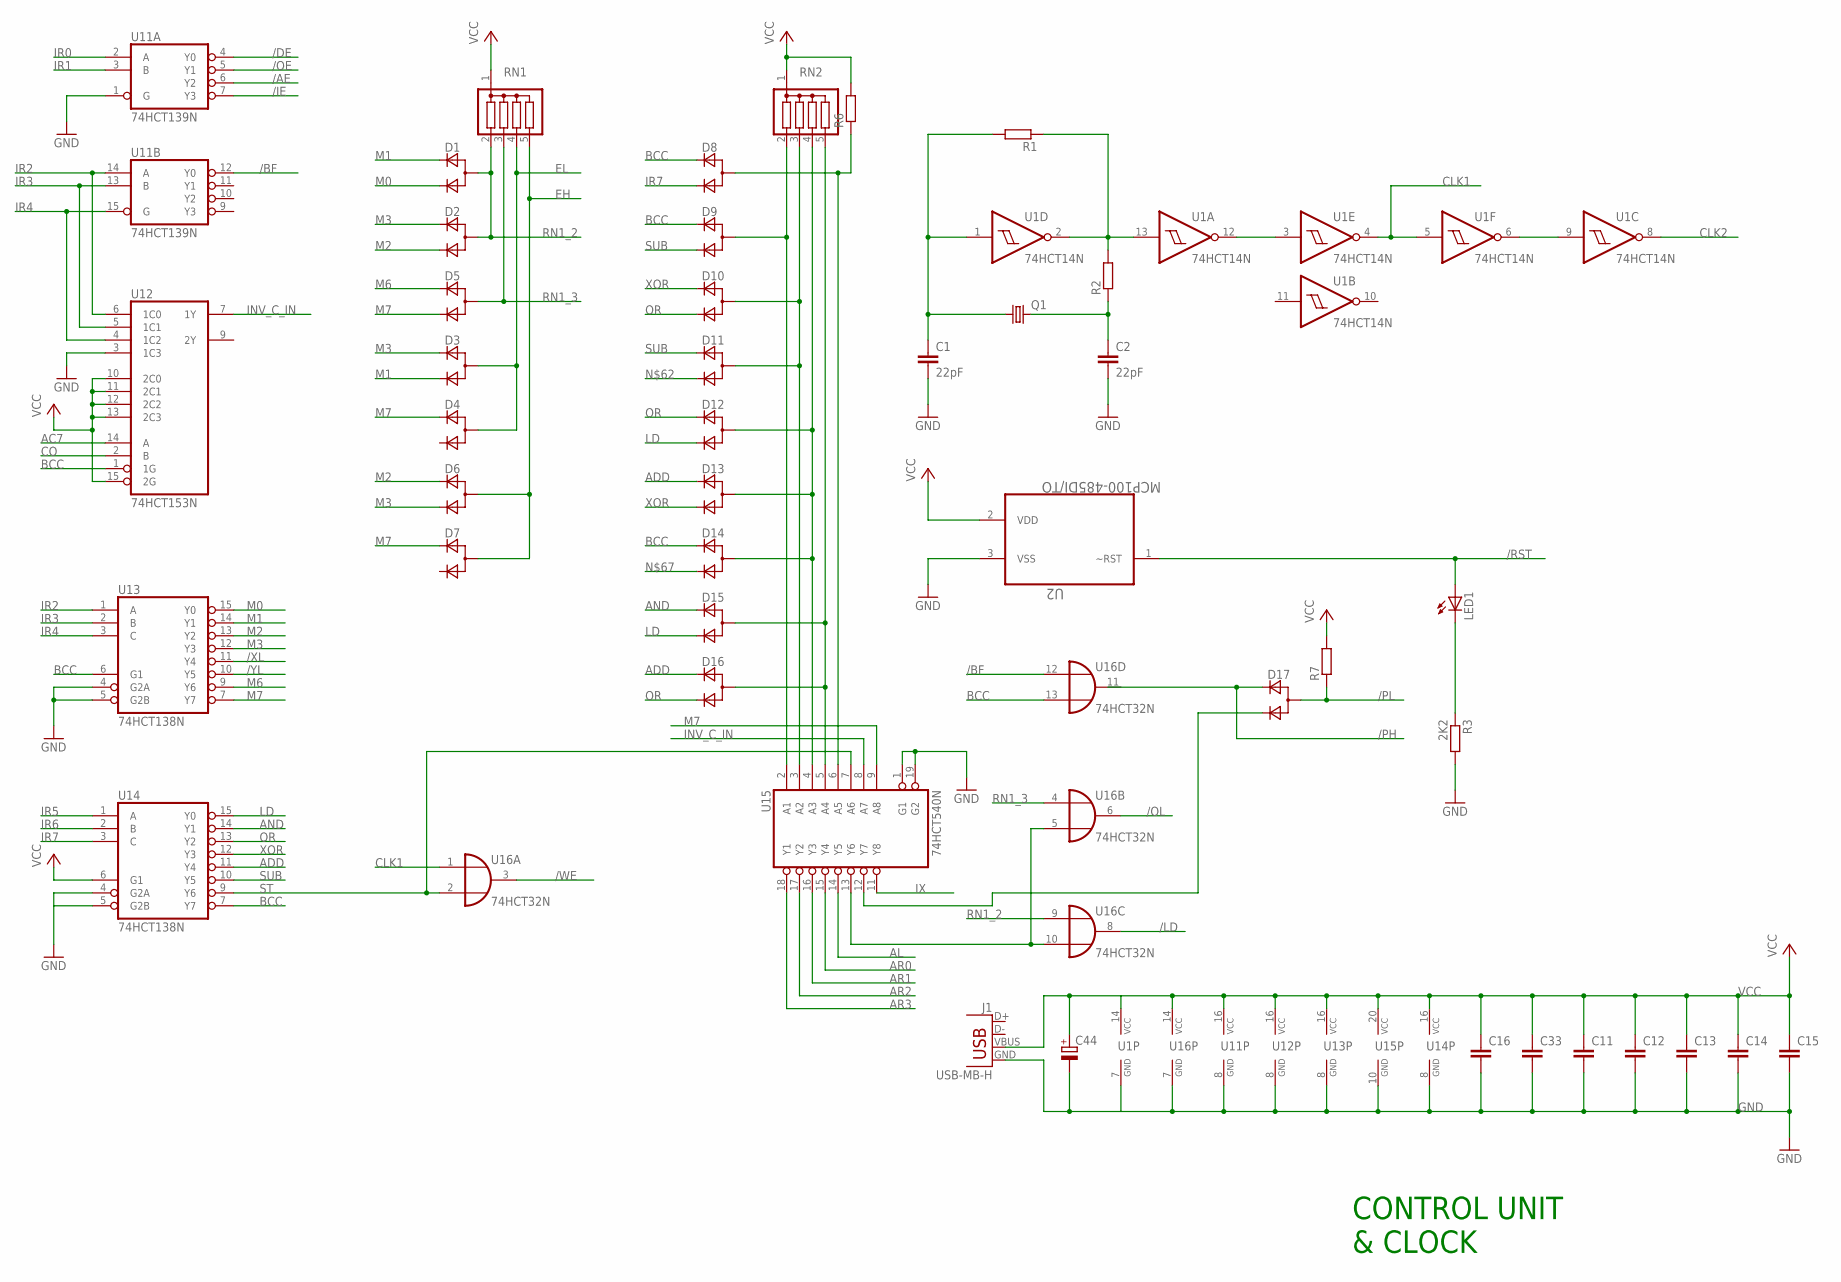
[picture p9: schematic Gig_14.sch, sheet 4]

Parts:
C1, C2: 22pF; RCL_C025-024X044
C11, C12, C13, C14, C15, C16, C33: RCL_C-EU025-024X044; RCL_C025-024X044
C44: CPOL-EUE5-8.5; E5-8,5
D1, D2, D3, D4, D5, D6, D7, D8, D9, D10, D11, D12, D13, D14, D15, D16, D17: D_2CSOT23; SOT-23
J1: USB-MB-H
LED1: LED_LED3MM
Q1: CRYSTALHC49S; HC49/S
R1, R2, R7: R-EU_0207/7; 0207/7
R3: 2K2; 0207/7
R6: R-EU_0207/12; 0207/12
RN1, RN2: G04R; SIL5
U1: 74HCT14N; DIL14
U2: MCP100-485DI/TO; TO127P254X495-3
U11: 74HCT139N; DIL16
U12: 74HCT153N; DIL16
U13, U14: 74HCT138N; DIL16
U15: 74HCT540N; DIL20
U16: 74HCT32N; DIL14

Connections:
/AE: U11.6 (Y2); also elsewhere on the board
/BF: U11.12 (Y0), U16.12 (I0)
/DE: U11.4 (Y0); also elsewhere on the board
/IE: U11.7 (Y3); also elsewhere on the board
/LD: U16.8 (O); also elsewhere on the board
/OE: U11.5 (Y1); also elsewhere on the board
/OL: U16.6 (O); also elsewhere on the board
/PH: D17.2 (C1); also elsewhere on the board
/PL: D17.1 (A), R7.1; also elsewhere on the board
/RST: LED1.A, U2.1 (~RST); also elsewhere on the board
/WE: U16.3 (O); also elsewhere on the board
/XL: U13.11 (Y4); also elsewhere on the board
/YL: U13.10 (Y5); also elsewhere on the board
AC7: U12.14 (A); also elsewhere on the board
ADD: D13.2 (C1), D16.2 (C1), U14.11 (Y4)
AL: U15.14 (Y5); also elsewhere on the board
AND: D15.2 (C1), U14.14 (Y1)
AR0: U15.15 (Y4); also elsewhere on the board
AR1: U15.16 (Y3); also elsewhere on the board
AR2: U15.17 (Y2); also elsewhere on the board
AR3: U15.18 (Y1); also elsewhere on the board
BCC: D8.2 (C1), D9.2 (C1), D14.2 (C1), U12.1 (1G), U13.6 (G1), U14.7 (Y7), U16.13 (I1)
CLK1: U1.4 (O), U1.5 (I), U16.1 (I0); also elsewhere on the board
CLK2: U1.8 (O); also elsewhere on the board
CO: U12.2 (B); also elsewhere on the board
EH: D6.1 (A), D7.1 (A), RN1.5; also elsewhere on the board
EL: D3.1 (A), D4.1 (A), RN1.4; also elsewhere on the board
GND: C1.2, C2.2, C11.2, C12.2, C13.2, C14.2, C15.2, C16.2, C33.2, C44.-, J1.GND, R3.2, U1.7 (GND), U2.3 (VSS), U11.1 (G), U11.8 (GND), U12.3 (1C3), U12.8 (GND), U13.4 (G2A), U13.5 (G2B), U13.8 (GND), U14.4 (G2A), U14.5 (G2B), U14.8 (GND), U15.1 (G1), U15.10 (GND), U15.19 (G2), U16.7 (GND); also elsewhere on the board
INV_C_IN: U12.7 (1Y), U15.8 (A7)
IR0: U11.2 (A); also elsewhere on the board
IR1: U11.3 (B); also elsewhere on the board
IR2: U11.14 (A), U12.6 (1C0), U13.1 (A); also elsewhere on the board
IR3: U11.13 (B), U12.5 (1C1), U13.2 (B); also elsewhere on the board
IR4: U11.15 (G), U12.4 (1C2), U13.3 (C); also elsewhere on the board
IR5: U14.1 (A); also elsewhere on the board
IR6: U14.2 (B); also elsewhere on the board
IR7: D8.3 (C2), U14.3 (C); also elsewhere on the board
IX: U15.11 (Y8); also elsewhere on the board
LD: D12.3 (C2), D15.3 (C2), U14.15 (Y0)
M0: D1.3 (C2), U13.15 (Y0)
M1: D1.2 (C1), D3.3 (C2), U13.14 (Y1)
M2: D2.3 (C2), D6.2 (C1), U13.13 (Y2)
M3: D2.2 (C1), D3.2 (C1), D6.3 (C2), U13.12 (Y3)
M6: D5.2 (C1), U13.9 (Y6)
M7: D4.2 (C1), D5.3 (C2), D7.2 (C1), U13.7 (Y7), U15.9 (A8)
unnamed: D8.1 (A), R6.1, U15.6 (A5)
unnamed: C1.1, Q1.1, R1.2, U1.1 (I)
unnamed: D17.3 (C2), U15.12 (Y7)
unnamed: C2.1, Q1.2, R2.1
unnamed: R1.1, R2.2, U1.2 (O), U1.13 (I)
unnamed: D9.1 (A), RN2.2, U15.2 (A1)
unnamed: D10.1 (A), D11.1 (A), RN2.3, U15.3 (A2)
unnamed: D12.1 (A), D13.1 (A), D14.1 (A), RN2.4, U15.4 (A3)
unnamed: D15.1 (A), D16.1 (A), RN2.5, U15.5 (A4)
unnamed: U1.3 (I), U1.12 (O)
unnamed: U15.13 (Y6), U16.5 (I1), U16.10 (I1)
unnamed: LED1.K (C), R3.1
unnamed: U1.6 (O), U1.9 (I)
OR: D10.3 (C2), D12.2 (C1), D16.3 (C2), U14.13 (Y2)
RN1_2: D1.1 (A), D2.1 (A), RN1.2, U16.9 (I0)
RN1_3: D5.1 (A), RN1.3, U16.4 (I0)
ST: U14.9 (Y6), U15.7 (A6), U16.2 (I1)
SUB: D9.3 (C2), D11.2 (C1), U14.10 (Y5)
VCC: C11.1, C12.1, C13.1, C14.1, C15.1, C16.1, C33.1, C44.+, J1.VBUS, R6.2, R7.2, RN1.1, RN2.1, U1.14 (VCC), U2.2 (VDD), U11.16 (VCC), U12.10 (2C0), U12.11 (2C1), U12.12 (2C2), U12.13 (2C3), U12.15 (2G), U12.16 (VCC), U13.16 (VCC), U14.6 (G1), U14.16 (VCC), U15.20 (VCC), U16.14 (VCC); also elsewhere on the board
XOR: D10.2 (C1), D13.3 (C2), U14.12 (Y3)

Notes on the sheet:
CONTROL UNIT & CLOCK

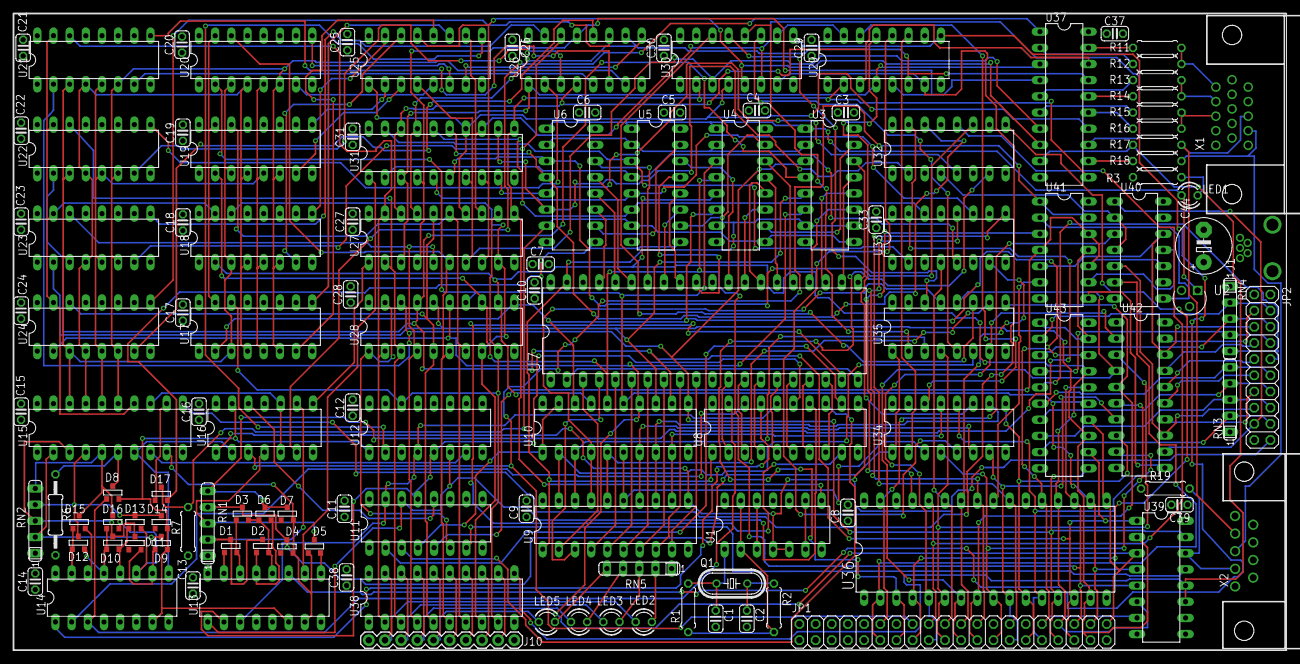
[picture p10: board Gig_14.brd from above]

Board: 4 copper layers, 199.9 x 100.0 mm, 127 parts (0 on the bottom side), 234 nets.

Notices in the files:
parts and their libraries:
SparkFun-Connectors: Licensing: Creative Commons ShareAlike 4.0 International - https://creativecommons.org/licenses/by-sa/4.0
